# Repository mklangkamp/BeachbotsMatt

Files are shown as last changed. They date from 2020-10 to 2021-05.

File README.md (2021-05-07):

# beachbots2020
This is the repository for the BeachBots MQP 2020
## Dependencies

### RPi.GPIO
Run on the Smallbot
```
sudo apt-get update
```
```
sudo apt-get install rpi.gpio
```

### Apriltag for Python 2
Run on the Basebot
```
sudo apt-get update
```
```
pip install apriltag
```

### Computer Vision
Everything needed to be installed for the computer vision can be found [here](https://coral.ai/docs/accelerator/get-started/#3-run-a-model-using-the-tensorflow-lite-api). Specifically run all the commands under the "On Linux" header.

## Code Architecture

### base_bot Package
This is where all the Basebot code is. The main file is the RunBaseBot.py
file. This package includes the AprilTag recognition, robot state machine,
and TCP communication to send data to the Smallbot.

### small_bot Package
This package contains everything needed for the smallbot. The main file is
the RunSmallBot.py file. This package includes the computer vision for trash
detection, chassis and arm actuation scripts, and TCP communication to
receive data from the Basebot.

### esp32_wifi Package
This package contains the .ino script needed to use the ESP32 as a wireless AP.

### Support Package
This package has just anything that does not fit the other categories
and are useful. However the highlight of this package is the Constants.py 
file. This essential file holds all the constants of the project and makes 
them global. This allows for easy changes across the project.

## How To Launch Basebot and Smallbot Code
*Note the password on the Rasberry Pi is "bots2021" and "!bob2020" for the Jetson

To launch the Smallbot with all the code, ssh into the Smallbot and type:
```
cd beachbots2020/Code/small_bot
```
```
unset DISPLAY XAUTHORITY
```
```
xvfb-run python3 RunSmallBot.py 
```
To launch the Basebot with all the code, from the Basebot type:
```
cd beachbots2020/Code/base_bot
```
```
python RunBaseBot.py
```

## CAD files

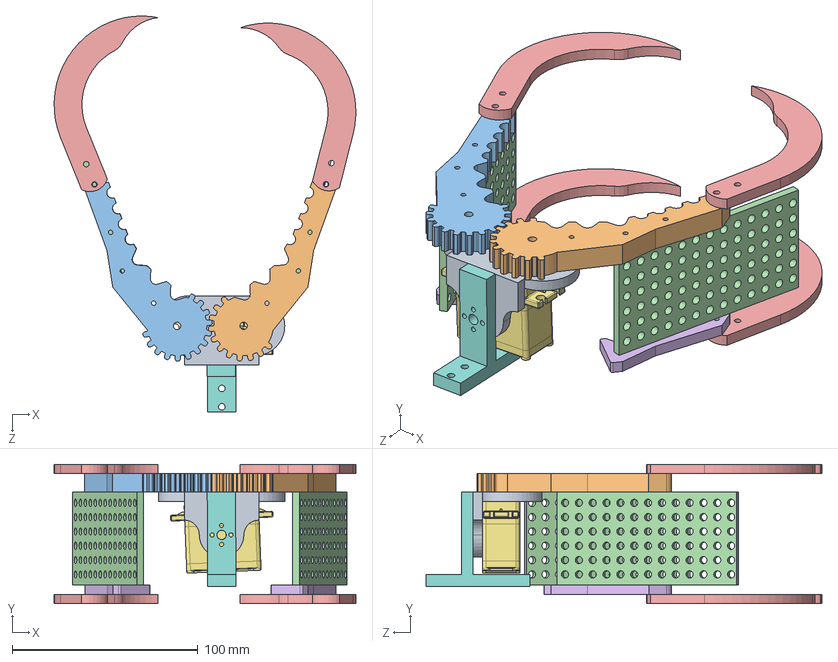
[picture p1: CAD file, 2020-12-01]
Chassis/New Gripper Designs/NewGripper1.SLDASM
162.5 x 75.0 x 213.3 mm
Gripper_Connector
Gripper_Finger_Driver
Gripper_Finger_Driven
SiftPlate x 2
Finger_Extension x 4
Gripper_Finger x 2
Servo 20kg elbow and gripper
GripperArmBracket

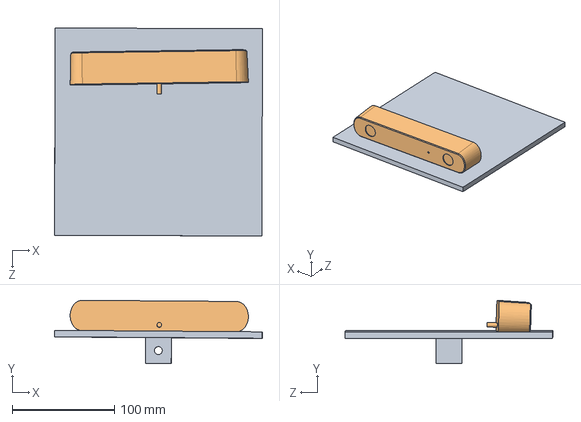
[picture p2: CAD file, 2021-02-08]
Basebot Stand/StandTopAssembly.SLDASM
203.8 x 62.1 x 203.8 mm
StandTop
ZEDCamera

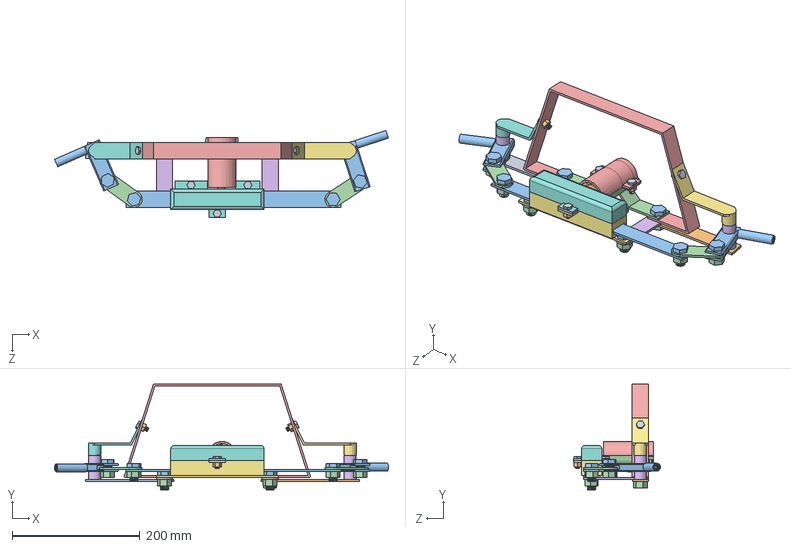
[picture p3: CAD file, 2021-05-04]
Basebot/Steering Mechanism.SLDASM
522.6 x 165.3 x 136.4 mm
Pinon Gear
37d-gearmotor-100-131-150-encoder
Rack
Control Arm x 2
Front Wheel Bracket
Short Rack Support Structure x 2
Long Rack Support Structure
Long Rack Support Structure (Top)
Pivot Arm (Left)
Pivot Arm (Right)
Front Wheel Axles x 2
Steering Motor Mount (Bottom)
Steering Motor Mount (Top)
Spacer x 4
Front Wheel Support
Front Wheel Support #2
0.25in Hex Bolt x 7
0.25in Nut x 7
0.5in Hex Bolt x 8
0.5in Nut x 8

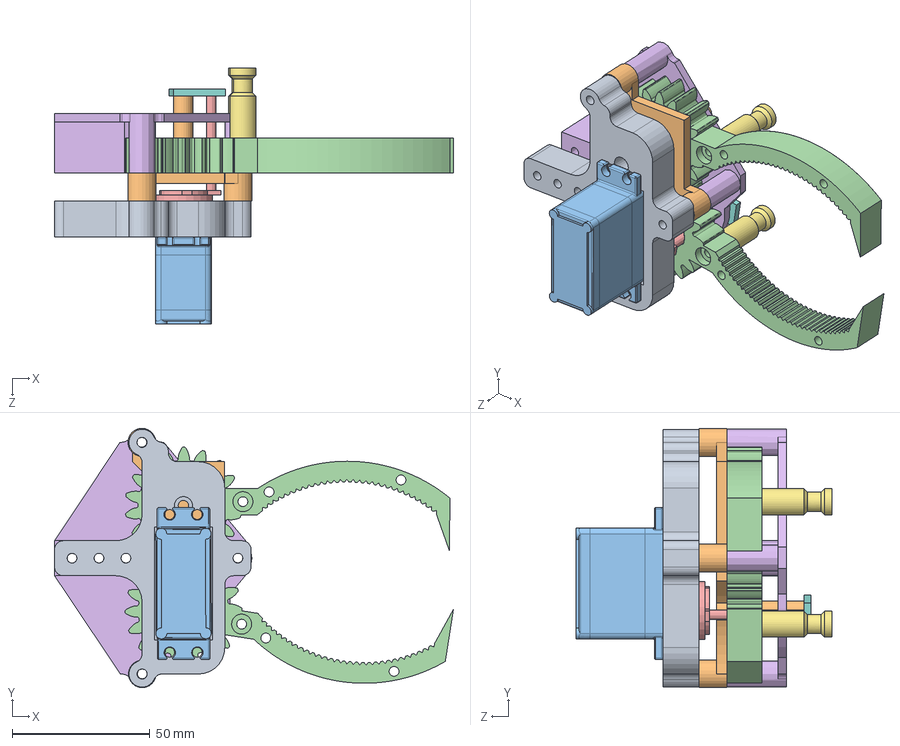
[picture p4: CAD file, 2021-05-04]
Chassis/GripperAssemblySlot/GripperSlotAssemblyNoTop.SLDASM
144.7 x 94.1 x 92.8 mm
ServoHolderBracketNew
MiddlePlate
Servo 20kg elbow and gripper2
NewFingerSlot x 2
ServoHornWithSlotAttachment
GripperTopBracketNew
RubberBandStandOff x 2
Connector Bracket

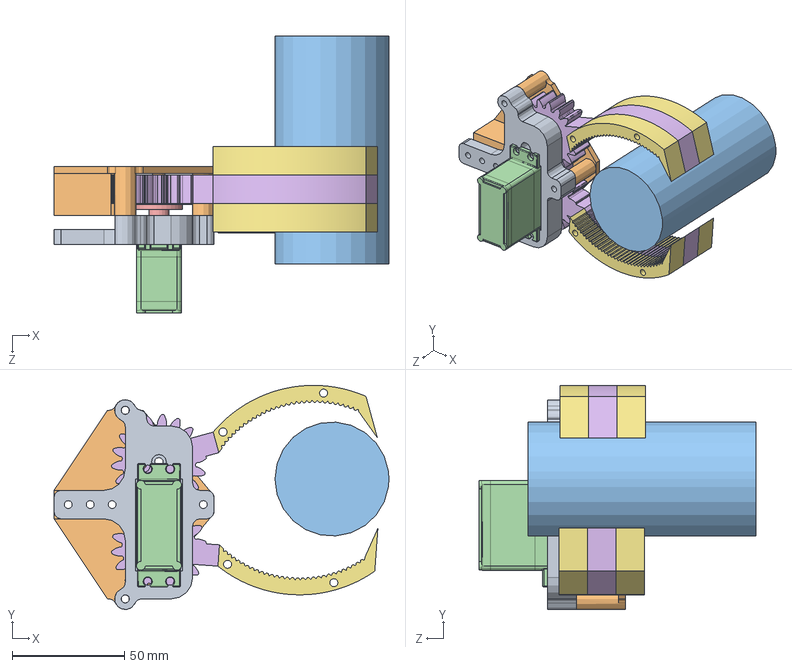
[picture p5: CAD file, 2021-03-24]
Chassis/GrippperAssemblyNEW/GrippperAssembly.SLDASM
149.2 x 99.9 x 123.4 mm
GripperRedesign
GripperRedesign2
bottle
Servo 20kg elbow and gripper2
horn
Involute Spur Gear Generator - Better 0 3-13 EXTRA x 2
Involute Spur Gear Generator - Better 0 3-13 WIDER x 4

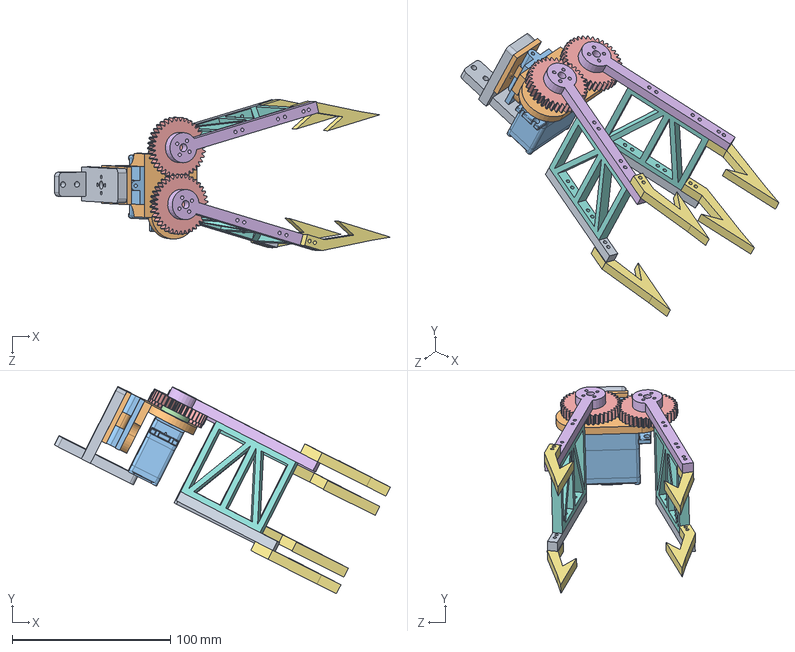
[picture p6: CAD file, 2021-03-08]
Chassis/New Gripper Designs/GripperRedesignOne/NewGripper.SLDASM
212.1 x 130.9 x 95.5 mm
GripperArmBracket
Gripper_Connector
Servo 20kg elbow and gripper
ServoHorn
NewGear x 2
FingerTop x 2
FingerOne x 4
Plate x 2
FingerBottom x 2
SpringLoadArm
SpringLoadGripper

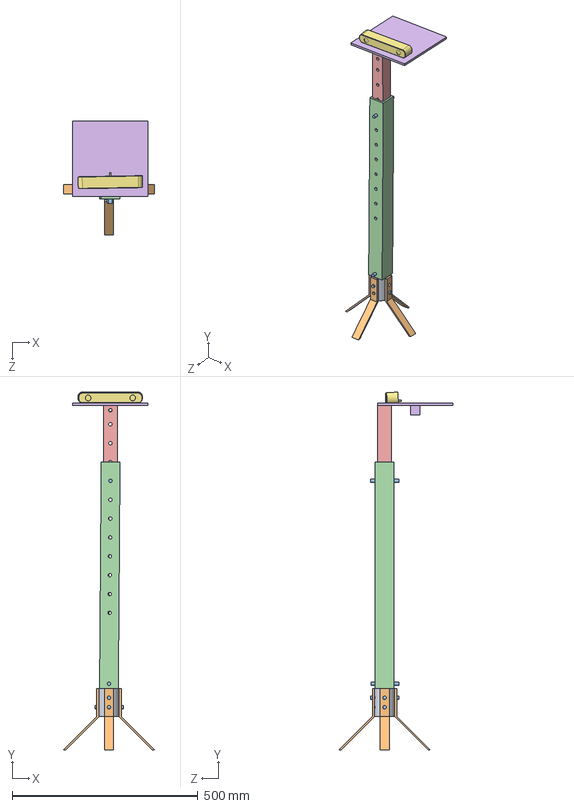
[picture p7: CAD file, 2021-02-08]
Basebot Stand/StandaloneStandAssembly.SLDASM
246.2 x 964.1 x 307.3 mm
StandBottomLegConnector
StandBottomLeg x 4
38inPin x 4
StandOuterShaft
StandInnerShaft
StandTop
ZEDCamera

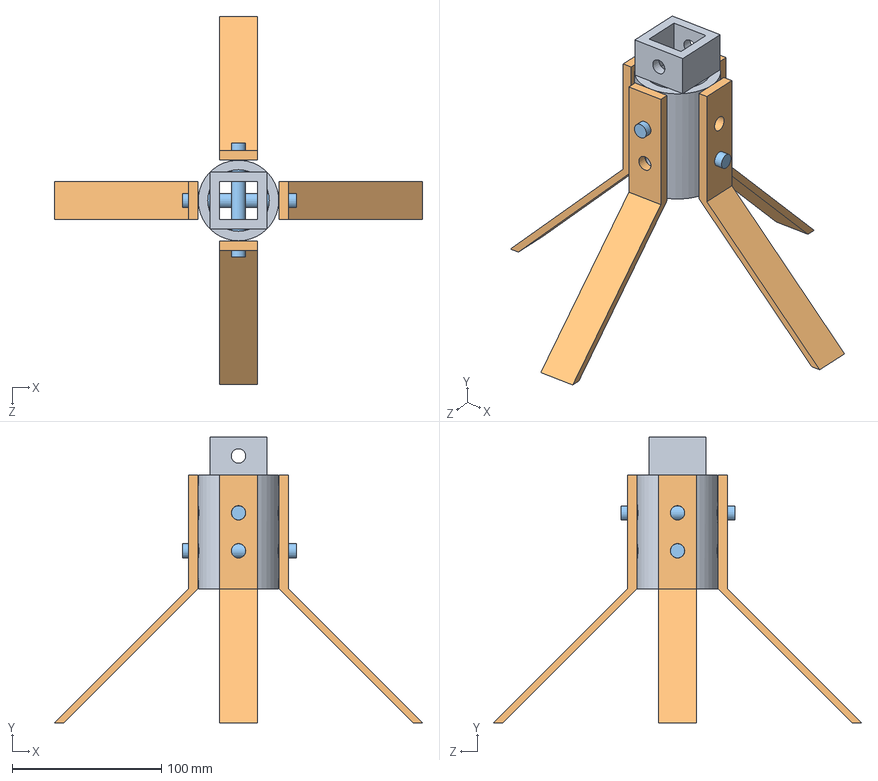
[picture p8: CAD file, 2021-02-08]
Basebot Stand/StandBottomLegAssembly.SLDASM
246.2 x 191.3 x 246.2 mm
StandBottomLegConnector
StandBottomLeg x 4
38inPin x 2

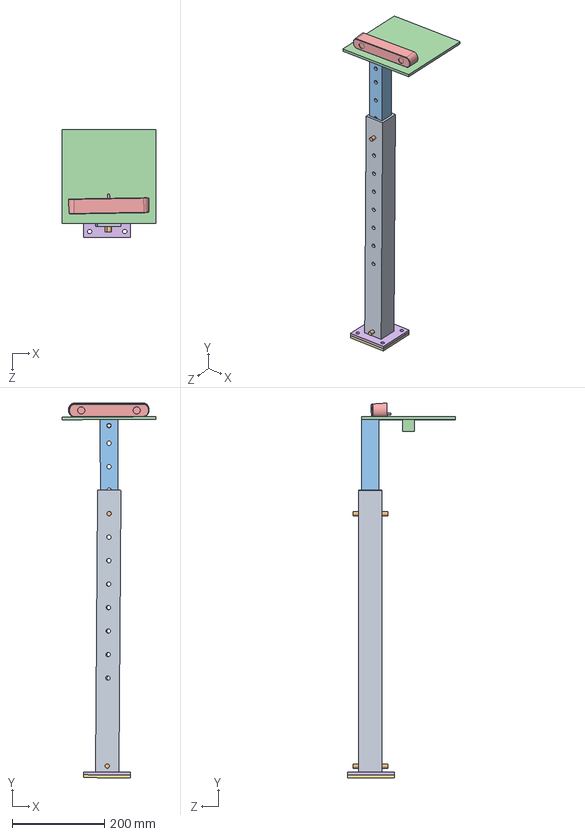
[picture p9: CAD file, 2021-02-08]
Basebot Stand/CartStandAssembly.SLDASM
203.2 x 811.2 x 233.1 mm
StandOuterShaft
38inPin x 2
StandInnerShaft
StandTop
ZEDCamera
StandBottomCartConnector
StandBottomCartBracket

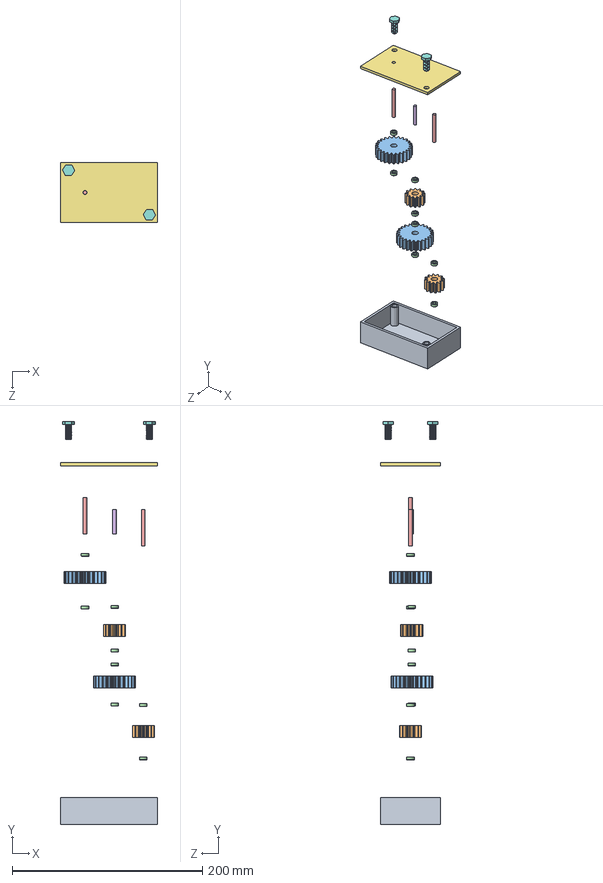
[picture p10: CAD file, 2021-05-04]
Basebot/Gearbox.SLDASM
101.6 x 423.2 x 63.5 mm
Gearbox Bottom
Gearbox - 12T x 2
Gearbox - 24T x 2
R155-2RS Mini ball Bearing x 8
2in Axle x 2
1in Axle
Gearbox Lid
0.25in Hex Bolt x 2

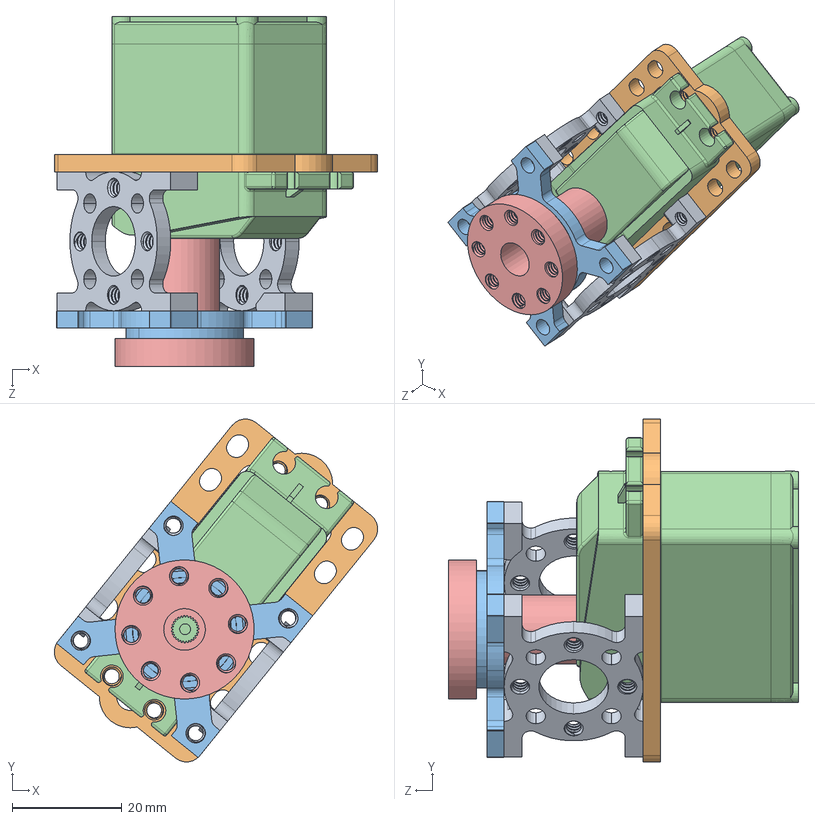
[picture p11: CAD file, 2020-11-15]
Chassis/Servo block subassembly.SLDASM
59.0 x 62.6 x 63.9 mm
Side Tapped Pattern Mount A - 545420 x 2
Standard Servo Plate A (575112)
.5in pillow block
Servo 20kg elbow and gripper
Servo Hub Shafts 25T (525123)

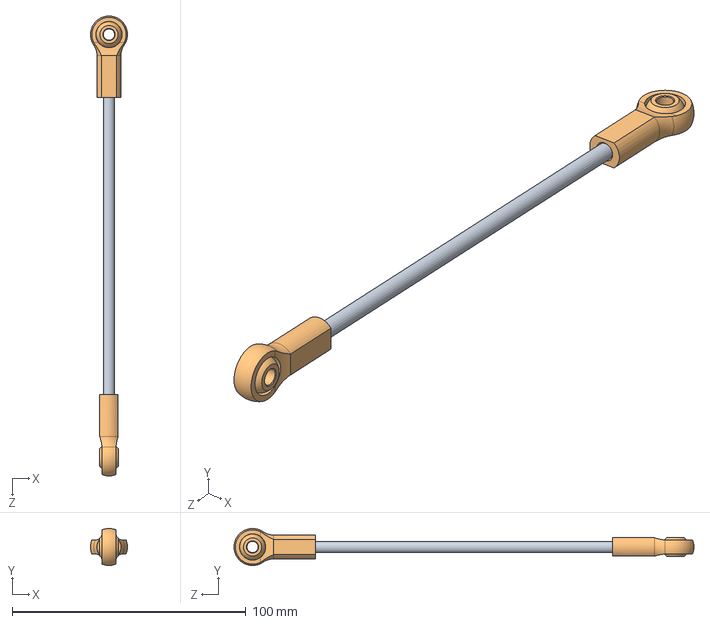
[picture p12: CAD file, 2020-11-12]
Chassis/Back suspension assembly.SLDASM
15.8 x 15.8 x 196.9 mm
6in 10-32 threaded rod
60645K311_STEEL BALL JOINT ROD END 10-32 x 2

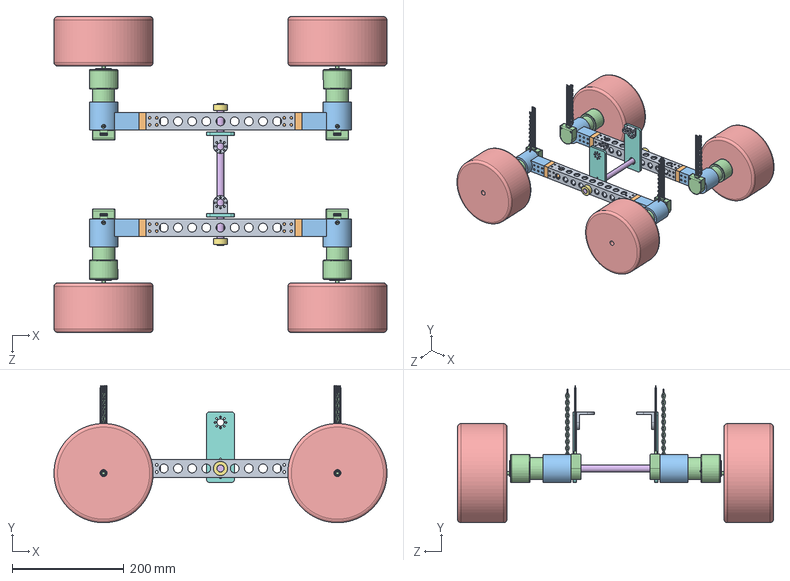
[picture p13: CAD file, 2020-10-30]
Chassis/Drivetrain assembly.SLDASM
596.9 x 246.4 x 566.5 mm
10.5in box extrusion x 2
Extrusion to motor mount adapter x 4
Motor mount x 4
GM9236S025-R1-SP_dc_motor_CAD x 4
wheel x 4
suspension shaft
0.5in shaft collar x 2
Pillow Block x 2
L bracket 545400 x 2

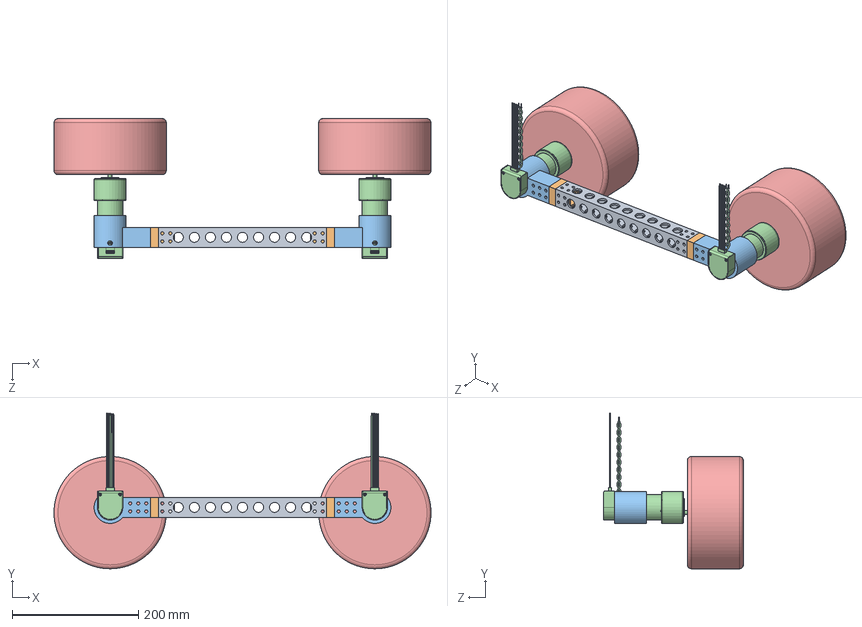
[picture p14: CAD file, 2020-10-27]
Chassis/One side drivetrain subassembly.SLDASM
596.9 x 246.4 x 221.4 mm
10.5in box extrusion
Extrusion to motor mount adapter x 2
Motor mount x 2
GM9236S025-R1-SP_dc_motor_CAD x 2
wheel x 2

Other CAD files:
Chassis/.5in pillow block bearing.SLDASM
Basebot Stand/ZEDCamera.SLDPRT
Basebot/Steering Motor Mount (Bottom).SLDPRT
Chassis/CAM (Esprit)/SuspensionPlateAfter1.STL
Basebot Stand/38inPin.SLDPRT
Basebot Stand/StandBottomCartBracket.SLDPRT
Basebot Stand/StandBottomCartConnector.SLDPRT
Basebot Stand/StandBottomLeg.SLDPRT
Basebot Stand/StandBottomLegConnector.SLDPRT
Basebot Stand/StandInnerShaft.SLDPRT
Basebot Stand/StandOuterShaft.SLDPRT
Basebot Stand/StandTop.SLDPRT
Basebot/0.25in Hex Bolt.SLDPRT
Basebot/0.25in Nut.SLDPRT
Basebot/0.5in Hex Bolt.SLDPRT
Basebot/0.5in Nut.SLDPRT
Basebot/1in Axle.SLDPRT
Basebot/2in Axle.SLDPRT
Basebot/37d-gearmotor-100-131-150-encoder.SLDPRT
Basebot/Back Motor Housing #2.SLDPRT
Basebot/Back Motor Housing.SLDPRT
Basebot/Back Wheel Housing.SLDPRT
Basebot/Back Wheel Support.SLDPRT
Basebot/BaseBot Support Bar #1.SLDPRT
Basebot/BaseBot Support Bar #2.SLDPRT
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

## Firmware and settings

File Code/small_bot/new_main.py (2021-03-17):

from Chassis import Chassis
import socket
from time import sleep
from DriveDetect import DriveDetect
import sys
sys.path.insert(0, '/home/pi/beachbots2020/Code/support')

import Constants

chassis = Chassis(Constants.RPWMF, Constants.RPWMB, Constants.LPWMF, Constants.LPWMB, Constants.STEP, Constants.DIR, Constants.SWITCH, Constants.GRIPPER, Constants.ELBOW, Constants.BUCKET)
driveDetect = DriveDetect(chassis, Constants.RESOLUTION, Constants.VIEW_ANGLE)

'''
current_state = b'drive'
trash_detected = False
trash_count = 0
last_turn = ' '

TCP_IP = '192.168.4.2'
TCP_PORT = 5005
BUFFER_SIZE = 20  # Normally 1024, but we want fast response

s = socket.socket(socket.AF_INET, socket.SOCK_STREAM)
s.bind((TCP_IP, TCP_PORT))
s.listen(1)

conn, addr = s.accept()
print('Connection address:', addr)

recieved = ""

counter = 0
finished_clean = False
'''

#chassis.arm.servo.gripper(True)
#sleep(2)
#chassis.arm.servo.gripper(False)
#chassis.arm.pickup()

while True:
    #chassis.point_turn_IMU(0, 20)

    #driveDetect.cleanLitter()
    chassis.arm.servo.bucket(False)
    #driveDetect.object_detect.detect_litter()
    
    #chassis.driveStraightIMU(-20, 5)
'''
while not finished_clean or trash_count < 4:

    if trash_count >= 4:
        current_state = b'stop'

    # Constantly updating current yaw angle
    euler_angles = chassis.IMU.euler_from_quaternion()

    data = conn.recv(BUFFER_SIZE)

    if data != b'middle':
        current_state = data

    if current_state == b'drive':
        driveDetect.cleanLitter()
    elif current_state == b'turnleft':
        chassis.swing_turn_IMU(chassis, euler_angles, -180, 5, 50)
        if abs(-10 - euler_angles) < 0.5:
            current_state = b'drive'
    elif current_state == b'turnright':
        chassis.swing_turn_IMU(chassis, euler_angles, 180, 5, 50)
        if abs(10 - euler_angles) < 0.5:
            current_state = b'drive'
    elif current_state == b'stop':
        chassis.drive(0, 0)
        break

    conn.send(data)  # echo

conn.close()
'''

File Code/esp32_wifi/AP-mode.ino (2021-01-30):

#include <Preferences.h>
#include <WiFi.h>
#include <Esp32WifiManager.h>

//Create a wifi manager
WifiManager manager;
void setup() {
  manager.setupAP();// Always go straight into AP mode without doing a re-scan first
}

void loop() {
  // read the serial port for new passwords and maintain connections
  manager.loop();
  if (manager.getState() == Connected) {
    // use the Wifi Stack now connected and a device is connected to the AP
  }
}

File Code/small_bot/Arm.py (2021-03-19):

# title           :Arm.py
# description     :Class for the 2 DOF arm
# author          :Dennis Chavez Romero, Spencer Gregg
# date            :2021-02-05
# version         :0.1
# notes           :
# python_version  :3.7
# ==============================================================================
import RPi.GPIO as GPIO
import time
from time import sleep
from ServoController import ServoController
import sys
sys.path.insert(0, '/home/pi/beachbots2020/Code/support')
import Constants

class Arm:

    def __init__(self, STEP, DIR, SWITCH, GRIPPER, ELBOW, BUCKET):
        """
        Class constructor
        """

        # Pins for step pulse and direction
        self.STEP = STEP
        self.DIR = DIR

        # Pin for limit switch
        self.SWITCH = SWITCH

        # Instance of servo controller
        self.servo = ServoController(GRIPPER, ELBOW, BUCKET)

        # Set pin numbering system
        GPIO.setmode(GPIO.BOARD)

        # Disable warnings
        GPIO.setwarnings(False)

        # Setup pins as OUT for output and IN for input
        GPIO.setup(self.STEP, GPIO.OUT)
        GPIO.setup(self.DIR, GPIO.OUT)
        GPIO.setup(self.SWITCH, GPIO.IN)

        # Lambda function for sleeps with microseconds
        self.usleep = lambda x: time.sleep(x / 1000000.0)

        # Variable for angle of stepper motor at any point in time
        self.shoulder_current = 0.0

        # Calibrate arm joints upon instantiation
        self.calibrate()

    def move_shoulder_angle(self, angle):
        """
        Moves the stepper motor to given angle (in degrees)
        :param angle     [int]  The angle to move the stepper motor to (in degrees).
        """

        # Calculate the target angle to go from the current angle
        target = angle - self.shoulder_current

        # Calculate the number of steps to achieve the calculated target
        steps = abs(int(target // Constants.STEP_ANGLE))

        num_steps = 0

        # Determine direction that the motor needs to go to based on target sign
        if target < 0:
            # If needs to go to a negative angle
            # Then set DIR(ection) to LOW
            GPIO.output(self.DIR, GPIO.LOW)
        else:
            # If needs to go to a positive angle
            # Then set DIR(ection) to HIGH
            GPIO.output(self.DIR, GPIO.HIGH)

        # Keep moving arm while the number of steps needed to get to target has not been achieved
        while num_steps < steps:
            GPIO.output(self.STEP, GPIO.HIGH)
            self.usleep(500)
            GPIO.output(self.STEP, GPIO.LOW)
            self.usleep(500)
            num_steps += 1

        # Update current shoulder angle
        self.shoulder_current += target

    def calibrate(self):
        """
        Zeros stepper motor and sets servo values to default
        """

        # Set bucket to default position
        self.servo.bucket(False)

        # Set elbow servo to its default pose
        self.servo.elbow(Constants.UP_POSE_ELBOW)

        # Set gripper to closed position
        self.servo.gripper(False)

        # Set the DIR pin to low
        GPIO.output(self.DIR, GPIO.LOW)

        # Keep driving the stepper motor down while it has not hit the limit switch
        while not GPIO.input(self.SWITCH):
            GPIO.output(self.STEP, GPIO.HIGH)
            self.usleep(500)
            GPIO.output(self.STEP, GPIO.LOW)
            self.usleep(500)

        # Once the limit switch has been toggled, we can zero the current shoulder angle
        self.shoulder_current = 0

        # Move the arm to an angle of 30 to be parallel with the ground
        self.move_shoulder_angle(30)

    def pickup(self):
        """
        Executes the motions needed to pickup a piece of trash.
        """

        # Elevate the shoulder
        self.move_shoulder_angle(100)
        sleep(2)

        # Open gripper
        self.servo.gripper(True)
        sleep(4)

        # Set the elbow to its pickup pose
        self.servo.elbow(Constants.DOWN_POSE_ELBOW)
        sleep(3)

        # Lower shoulder
        self.move_shoulder_angle(45)

        # Close gripper
        self.servo.gripper(False)
        sleep(3)

        # Elevate elbow towards bucket
        self.servo.elbow(Constants.UP_POSE_ELBOW)

        # Elevate shoulder
        self.move_shoulder_angle(115)
        sleep(2)

        # Open gripper
        self.servo.gripper(True)
        sleep(3)

        # Bring shoulder back to its original position
        self.move_shoulder_angle(30)

        # Close gripper
        self.servo.gripper(False)

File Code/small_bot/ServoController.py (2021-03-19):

# title           :ServoController.py
# description     :Controller for onboard servos connected to the Maestro Controller
# author          :Dennis Chavez Romero, Spencer Gregg, Yossef Naim
# date            :2020-12-05
# version         :0.1
# notes           :
# python_version  :3.7
# ==============================================================================
import Maestro
import sys
sys.path.insert(0, '/home/pi/beachbots2020/Code/support')
import Constants


class ServoController:
    def __init__(self, GRIPPER, ELBOW, BUCKET):
        """
        Class constructor
        """

        # Instance of Maestro controller
        self.servo = Maestro.Controller()

        # Controller pins
        self.gripper_pin = GRIPPER
        self.elbow_pin = ELBOW
        self.bucket_pin = BUCKET

        self.delay = 0.001

    def gripper(self, val, accel=5, speed=15):
        """
        :param val       [bool] True opens the gripper, False closes the gripper.
        :param accel     [int]  Acceleration of servo.
        :param speed     [int]  Speed of servo movement.
        """

        # Set gripper acceleration
        self.servo.setAccel(self.gripper_pin, accel)

        # Set gripper speed
        self.servo.setSpeed(self.gripper_pin, speed)

        if val:
            self.servo.setTarget(self.gripper_pin, Constants.GRIPPER_OPEN_VAL)
        else:
            self.servo.setTarget(self.gripper_pin, Constants.GRIPPER_CLOSED_VAL)

    def get_gripper_pos(self):
        """
        Getter for gripper position
        :return        [int] Position of the gripper
        """

        # Get the current position of gripper servo
        return self.servo.getPosition(self.gripper_pin)

    def bucket(self, val, accel=15, speed=45):
        """
        :param val       [bool] True opens the bucket, False closes the bucket.
        :param accel     [int]  Acceleration of servo.
        :param speed     [int]  Speed of servo movement.
        """

        # Set bucket acceleration
        self.servo.setAccel(self.bucket_pin, accel)

        # Set bucket speed
        self.servo.setSpeed(self.bucket_pin, speed)

        if val:
            self.servo.setTarget(self.bucket_pin, Constants.BUCKET_DISPOSE_VAL)
        else:
            self.servo.setTarget(self.bucket_pin, Constants.BUCKET_DEFAULT_VAL)

    def get_bucket_pos(self):
        """
        Getter for bucket position
        :return        [int] Position of the bucket
        """

        # Get the current position of bucket servo
        return self.servo.getPosition(self.bucket_pin)

    def elbow(self, val, accel=5, speed=15):
        """
        :param val       [int]  Position for the elbow to go to.
        :param accel     [int]  Acceleration of servo.
        :param speed     [int]  Speed of servo movement.
        """

        # Set elbow acceleration
        self.servo.setAccel(self.elbow_pin, accel)

        # Set servo speed
        self.servo.setSpeed(self.elbow_pin, speed)

        # Set elbow position value
        self.servo.setTarget(self.elbow_pin, val)

    def get_elbow_pos(self):
        """
        Getter for elbow position
        :return        [int] Position of the elbow
        """

        # Get the current position of elbow servo
        return self.servo.getPosition(self.elbow_pin)

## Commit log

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2020-10-27 box extrusion for drivetrain
    box extrusion
    [10.5in box extrusion.SLDPRT]
2020-10-27 made new folder
    chassis folder
    [10.5in box extrusion.SLDPRT]
2020-10-27 Extusion almost complete, adapter complete
    10.5in extrusion and adapter between motor and extrusion
    [10.5in box extrusion.SLDPRT, Extrusion to motor mount adapter.SLDPRT]
2020-10-27 Motor Mount and extrusion completed
    motor mount and extrusion done
    [10.5in box extrusion.SLDPRT, Motor mount.SLDPRT]
2020-10-27 Started assembly of drivetrain and subassemblies
    drivetrain assemblies
    [Drivetrain assembly.SLDASM, One side drivetrain subassembly.SLDASM, suspension shaft.SLDPRT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]
2020-10-30 Started on adding pillow blocks
    started adding pillow blocks to chassis
    [Drivetrain assembly.SLDASM, L bracket 545400.SLDPRT, Pillow Block.SLDPRT]
2020-10-30 Added more parts
    continued to make parts for the drivetrain
    [.5in pillow block bearing.SLDASM, Pillow Block.SLDPRT, Top plate.SLDPRT]
2020-10-31 Added top plate to drivetrain assembly added new parts
    Added top plate to drivetrain assembly added new parts
    [.5in pillow block bearing.SLDASM, 60645K311_STEEL BALL JOINT ROD END 10-32.SLDPRT, 90322A644_HIGH-STRENGTH STEEL THREADED ROD 6in.SLDPRT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]
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2020-11-06 Made new top plate called top plate 2
    New top plate
    [Top plate 2.SLDPRT]
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2020-11-09 Minor changes to battery mount and assembly
    minor changes
    [Top plate 2.SLDPRT, battery mount.SLDPRT]
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2020-11-12 Fixed orientation of top and bottom bucket. Added to Drivetrain Assembly.
    [Back suspension assembly.SLDASM, Bucket - Bottom.SLDPRT, Bucket - Top.SLDPRT]
2020-11-12 Added spacer for top part
    New top part
    [12V 16Ah Battery.SLDPRT, top piece spacer.SLDPRT, top plate spacer.SLDPRT]
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2020-11-16 Bucket complete with support parts
    completed the bucket and added some support parts
    [1.75in standoff post.SLDPRT, Bucket Bottom Spencer.SLDPRT, Bucket side wall 1.SLDPRT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]
2020-11-17 updated stepper motor mount
    made a few changes to the motor mount
    [Arm stepper motor mount.SLDPRT]
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2020-11-21 Started on Raspberry Pi mount
    raspberry pi mount
    [raspberry pi 4b mount.SLDPRT]
2020-11-23 New mounts for electronics as well as modified gripper design
    New mounts for electronics as well as modified gripper design
    [Finger_Extension.SLDPRT, Gripper_Connector.SLDPRT, Gripper_Finger.SLDPRT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]
2020-11-23 Update hbridge mount.SLDPRT
    Added supports for second hbridge on mount
    [hbridge mount.SLDPRT]
2020-11-25 edited pi4 mount
    made some changes to pi4 mount
    [raspberry pi 4b mount.SLDPRT]
2020-11-26 Smallbot camera completed
    camera done and added to assembly
    [Camera Mount with Servo.SLDPRT, Smallbot camera mount.SLDPRT]
2020-11-28 Stepper driver mount and servo controller completed and added to assem
    stepper driver mount and servo controller mount completed and added to assembly
    [Servo controller and stepper driver mount 2.SLDPRT, Servo controller and stepper driver mount.SLDPRT, hbridge mount.SLDPRT]
2020-11-28 new assembly w/ gripper
    New Assembly that contains gripper
    [GripperArmBracket.SLDPRT]
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2020-12-01 added voltage regulator mounts
    new voltage regulator mounts
    [GripperArmBracket.SLDPRT, NewGripper1.SLDASM, voltage regulator mounts.SLDPRT]
2020-12-03 new bottom part of bucket
    new design for bucket bottom
    [Bucket Bottom Spencer v2.SLDPRT]
2021-01-11 Completed bucket ramp
    Completed the bucket ramp to help with bottles/cans from getting stuck
    [bucket ramp.SLDPRT]
2021-01-21 Changed bucket bracket to make bucket higher
    Easier to help bottles from falling out of bucket when arm releases bottle/can
    [new bucket bracket.SLDPRT]
2021-01-22 edited bucket brackets for bottles/cans
    Made bucket brackets fan out to help with bottle/cans
    [new bucket bracket.SLDPRT]
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2021-01-31 Mount for IMU and limit switch for arm
    new 3d printed parts
    [Adafruit IMU mount.SLDPRT, Limit switch mount for arm.SLDPRT]
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2021-02-03 spacer for imu added
    new spacer for imu, added to assembly
    [3-8 spacer for imu.SLDPRT]
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2021-02-08 Basebot stand files
    Added files for basebot stand
    [38inPin.SLDPRT, CartStandAssembly.SLDASM, StandBottomCartBracket.SLDPRT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]
2021-02-10 Point turn function working, found issue with IMU
    point turn function working, fixed drive function. Found IMU has inconsistent yaw outputs.
    [AdafruitIMU.py, Chassis.py, Test.py]
2021-02-10 correct files from changes 2-9
    changed chassis drive, point turn functions. Tested gyro and euler angles found issue with IMU.
    [AdafruitIMU.py, Chassis.py, Test.py]
2021-02-11 Yaw working by converting quaternions
    working yaw code and avoids "None" outoput
    [AdafruitIMU.py, Test.py]
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2021-02-18 Code for running TCP communication with apriltags, sending to smallbot, and running functions on smallbot
    Corrected error of apriltag having to be visible for duration of the turn.
    [ServerTurn.py, tag_and_client.py]
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2021-02-21 Edited motor covers
    Motor covers were too thick changed to .125in
    [MotorCoverBracketTwo.SLDPRT]
2021-02-22 Create AprilTag Clip.SLDPRT
    AprilTag Clip (press fit because of the plastic)
    [AprilTag Clip.SLDPRT]
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2021-02-22 Changed motor cover thickness and completed apriltag mount
    changed motor cover thickness to .125 and finalized design for apriltag mount
    [Apriltag mount.SLDPRT, MotorCoverBracketOne.SLDPRT, MotorCoverBracketTwo.SLDPRT]
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2021-03-07 Smalllbot changes to for correct drive/turn commands
    Smallbot can now turn and drive based on basebot commands for correct camera view
    [Chassis.py, DriveDetect.py]
2021-03-08 Added gripper design and first arm reinforcement
    [FingerBottom.SLDPRT, FingerOne.SLDPRT, FingerTop.SLDPRT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]
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2021-03-19 Gripper Parts and Assemblies
    Gripper parts and assembly used for final testing
    [GripperRedesign.SLDPRT, GripperRedesign2.SLDPRT, GrippperAssembly.SLDASM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]
2021-03-20 Reverted to older commit
    [RunSmallBot.py]
2021-03-24 Create LBracketReinforcement.SLDPRT
    Made CAD for a reinforcement bracket for the L Bracket on the arm
    [LBracketReinforcement.SLDPRT]
2021-03-24 Made exploded views of drivetrain and arm subassemblies
    Solidworks subassemblies complete
    [GrippperAssembly.SLDASM, Involute Spur Gear Generator - Better 0 3-13 EXTRA.SLDPRT, Involute Spur Gear Generator - Better 0 3-13 WIDER.SLDPRT]
2021-03-30 Power switch mount for smallbot
    final power switch mount for the smallbot
    [power swtich mount.SLDPRT]
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2021-05-04 Newest gripper design & LBracket Reinforcement
    [Connector Bracket.SLDPRT, GripperSlotAssemblyNoTop.SLDASM, GripperTopBracketNew.SLDPRT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]
